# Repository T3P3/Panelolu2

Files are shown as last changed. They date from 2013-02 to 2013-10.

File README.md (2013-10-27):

Panelolu2
=========

An I2C control solution for Sanguinololu, Melzi and more

by tony@think3dprint3d.com

see
http://blog.think3dprint3d.com/2013/02/panelolu2.html
for details

GPL V3

Contents:

- Eagle files for the Panelolu2 circuit board.

- Eagle files for the Sanguinololu and Melzi adapter boards. 

- SCAD files for the case (note still a work in progress)

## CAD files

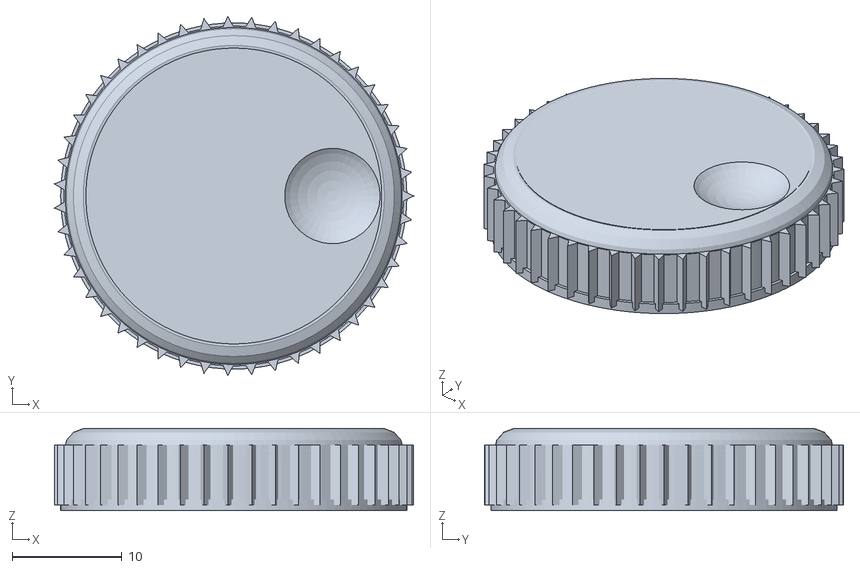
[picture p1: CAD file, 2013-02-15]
Knob_panelolu2.stl
32.8 x 32.8 x 7.50

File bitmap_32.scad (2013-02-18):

/*
Bitmap and 32Bit Font Module based on
Bitmap and 8Bit Font Module
Tony Buser <tbuser@gmail.com>
http://tonybuser.com
http://creativecommons.org/licenses/by/3.0/

Font mapped is Lucida Console fixed width - 32 bit high, 20 bit wide
Bitmap characters are 31 bits high and 8,16,24 or 32 bits wide

tony@think3dprint3d.com
http://blog.think3dprint3d.com/2013/02/bitmap32.html
*/

font_column_bits=31;
//font_row_bits=20; //varies

module bitmap(bitmap, block_size, height, column_bits, row_bits) {
	x_length = block_size * row_bits;
	y_length = block_size * column_bits;
	bitmap_size = row_bits * column_bits;

	function loc_y(loc) = floor(loc / row_bits) * block_size;
	function loc_x(loc) = loc % row_bits * block_size;
	function loc_z(loc) = (bitmap[loc]*height-height)/2;

	translate(v = [-x_length/2+block_size/2,-y_length/2+block_size/2,height/2]) {
		for (loc = [0:bitmap_size - 1]) {
			if (bitmap[loc] != 0) {
				union() {
					translate(v = [loc_x(loc), loc_y(loc), loc_z(loc)]) {
						cube(size = [block_size+0.01, block_size+0.01, height * bitmap[loc]], center = true);
						//echo(str("loc: ",loc," loc_x: ", loc_x(loc) , " loc_y: ",  loc_y(loc)));
					}
				}
			}
		}
	}
}

module 32bit_char(char, block_size, height) {
		if (char == "!") {
	 bitmap([
		0,0,0,0,0,0,0,0,      
		0,0,0,0,0,0,0,0,      
		1,1,1,1,1,0,0,0, 
		1,1,1,1,1,0,0,0, 
		1,1,1,1,1,0,0,0, 
		1,1,1,1,1,0,0,0, 
		1,1,1,1,1,0,0,0, 
		1,1,1,1,1,0,0,0, 
		1,1,1,1,1,0,0,0, 
		1,1,1,1,1,0,0,0, 
		1,1,1,1,1,0,0,0, 
		1,1,1,1,1,0,0,0, 
		1,1,1,1,1,0,0,0, 
		1,1,1,1,1,0,0,0, 
		1,1,1,1,1,0,0,0, 
		1,1,1,1,1,0,0,0, 
		1,1,1,1,1,0,0,0, 
		1,1,1,1,1,0,0,0, 
		1,1,1,1,1,0,0,0, 
		1,1,1,1,1,0,0,0, 
		1,1,1,1,1,0,0,0, 
		0,0,0,0,0,0,0,0,      
		0,0,0,0,0,0,0,0,      
		0,0,0,0,0,0,0,0,      
		1,1,1,1,1,0,0,0, 
		1,1,1,1,1,0,0,0, 
		1,1,1,1,1,0,0,0, 
		0,0,0,0,0,0,0,0,      
		0,0,0,0,0,0,0,0,      
		0,0,0,0,0,0,0,0,      
		0,0,0,0,0,0,0,0      
			], block_size, height, font_column_bits, 8);
	}
		else if (char == "\"") {
		 bitmap([
		1,1,1,1,1,0,1,1,1,1,1,0,0,0,0,0,  
		1,1,1,1,1,0,1,1,1,1,1,0,0,0,0,0,  
		1,1,1,1,1,0,1,1,1,1,1,0,0,0,0,0,  
		1,1,1,1,1,0,1,1,1,1,1,0,0,0,0,0,  
		1,1,1,1,1,0,1,1,1,1,1,0,0,0,0,0,  
		1,1,1,1,1,0,1,1,1,1,1,0,0,0,0,0,  
		1,1,1,1,1,0,1,1,1,1,1,0,0,0,0,0,  
		1,1,1,1,1,0,1,1,1,1,1,0,0,0,0,0,  
		0,0,0,0,0,0,0,0,0,0,0,0,0,0,0,0,            
		0,0,0,0,0,0,0,0,0,0,0,0,0,0,0,0,            
		0,0,0,0,0,0,0,0,0,0,0,0,0,0,0,0,            
		0,0,0,0,0,0,0,0,0,0,0,0,0,0,0,0,            
		0,0,0,0,0,0,0,0,0,0,0,0,0,0,0,0,            
		0,0,0,0,0,0,0,0,0,0,0,0,0,0,0,0,            
		0,0,0,0,0,0,0,0,0,0,0,0,0,0,0,0,            
		0,0,0,0,0,0,0,0,0,0,0,0,0,0,0,0,            
		0,0,0,0,0,0,0,0,0,0,0,0,0,0,0,0,            
		0,0,0,0,0,0,0,0,0,0,0,0,0,0,0,0,            
		0,0,0,0,0,0,0,0,0,0,0,0,0,0,0,0,            
		0,0,0,0,0,0,0,0,0,0,0,0,0,0,0,0,            
		0,0,0,0,0,0,0,0,0,0,0,0,0,0,0,0,            
		0,0,0,0,0,0,0,0,0,0,0,0,0,0,0,0,            
		0,0,0,0,0,0,0,0,0,0,0,0,0,0,0,0,            
		0,0,0,0,0,0,0,0,0,0,0,0,0,0,0,0,            
		0,0,0,0,0,0,0,0,0,0,0,0,0,0,0,0,            
		0,0,0,0,0,0,0,0,0,0,0,0,0,0,0,0,            
		0,0,0,0,0,0,0,0,0,0,0,0,0,0,0,0,            
		0,0,0,0,0,0,0,0,0,0,0,0,0,0,0,0,            
		0,0,0,0,0,0,0,0,0,0,0,0,0,0,0,0,            
		0,0,0,0,0,0,0,0,0,0,0,0,0,0,0,0,            
		0,0,0,0,0,0,0,0,0,0,0,0,0,0,0,0            
			], block_size, height, font_column_bits, 16);
	}
		else if (char == "#") {
		 bitmap([
		0,0,0,0,0,0,0,0,0,0,0,0,0,0,0,0,0,0,0,0,0,0,0,0,                        
		0,0,0,0,0,0,0,0,0,0,0,0,0,0,0,0,0,0,0,0,0,0,0,0,                        
		0,0,0,0,0,0,0,0,0,0,1,1,1,0,0,0,0,1,1,1,0,0,0,0,                  
		0,0,0,0,0,0,0,0,0,1,1,1,1,0,0,0,1,1,1,1,0,0,0,0,                
		0,0,0,0,0,0,0,0,0,1,1,1,0,0,0,0,1,1,1,0,0,0,0,0,                  
		0,0,0,0,0,0,0,0,0,1,1,1,0,0,0,0,1,1,1,0,0,0,0,0,                  
		0,0,0,0,0,0,0,0,0,1,1,1,0,0,0,0,1,1,1,0,0,0,0,0,                  
		0,0,0,0,0,0,0,0,1,1,1,1,0,0,0,1,1,1,1,0,0,0,0,0,                
		0,0,0,0,0,0,0,0,1,1,1,0,0,0,0,1,1,1,0,0,0,0,0,0,                  
		0,0,0,0,0,0,0,0,1,1,1,0,0,0,0,1,1,1,0,0,0,0,0,0,                  
		0,0,1,1,1,1,1,1,1,1,1,1,1,1,1,1,1,1,1,1,1,1,1,0,   
		0,0,1,1,1,1,1,1,1,1,1,1,1,1,1,1,1,1,1,1,1,1,1,0,   
		0,0,0,0,0,0,0,1,1,1,0,0,0,0,1,1,1,0,0,0,0,0,0,0,                  
		0,0,0,0,0,0,0,1,1,1,0,0,0,0,1,1,1,0,0,0,0,0,0,0,                  
		0,0,0,0,0,0,1,1,1,1,0,0,0,1,1,1,1,0,0,0,0,0,0,0,                
		0,0,0,0,0,0,1,1,1,0,0,0,0,1,1,1,0,0,0,0,0,0,0,0,                  
		0,0,0,0,0,0,1,1,1,0,0,0,0,1,1,1,0,0,0,0,0,0,0,0,                  
		1,1,1,1,1,1,1,1,1,1,1,1,1,1,1,1,1,1,1,1,1,0,0,0,   
		1,1,1,1,1,1,1,1,1,1,1,1,1,1,1,1,1,1,1,1,1,0,0,0,   
		0,0,0,0,0,1,1,1,0,0,0,0,1,1,1,0,0,0,0,0,0,0,0,0,                  
		0,0,0,0,0,1,1,1,0,0,0,0,1,1,1,0,0,0,0,0,0,0,0,0,                  
		0,0,0,0,1,1,1,1,0,0,0,1,1,1,1,0,0,0,0,0,0,0,0,0,                
		0,0,0,0,1,1,1,0,0,0,0,1,1,1,0,0,0,0,0,0,0,0,0,0,                  
		0,0,0,0,1,1,1,0,0,0,0,1,1,1,0,0,0,0,0,0,0,0,0,0,                  
		0,0,0,0,1,1,1,0,0,0,0,1,1,1,0,0,0,0,0,0,0,0,0,0,                  
		0,0,0,1,1,1,1,0,0,0,1,1,1,1,0,0,0,0,0,0,0,0,0,0,                
		0,0,0,1,1,1,0,0,0,0,1,1,1,0,0,0,0,0,0,0,0,0,0,0,                  
		0,0,0,0,0,0,0,0,0,0,0,0,0,0,0,0,0,0,0,0,0,0,0,0,                        
		0,0,0,0,0,0,0,0,0,0,0,0,0,0,0,0,0,0,0,0,0,0,0,0,                        
		0,0,0,0,0,0,0,0,0,0,0,0,0,0,0,0,0,0,0,0,0,0,0,0,                        
		0,0,0,0,0,0,0,0,0,0,0,0,0,0,0,0,0,0,0,0,0,0,0,0                        
			], block_size, height, font_column_bits, 24);
	}
		else if (char == "$") {
		 bitmap([
		0,0,0,0,0,0,0,1,1,1,0,0,0,0,0,0,             
		0,0,0,0,0,0,0,1,1,1,0,0,0,0,0,0,             
		0,0,0,0,0,1,1,1,1,1,1,1,1,0,0,0,        
		0,0,0,1,1,1,1,1,1,1,1,1,1,1,1,0,    
		0,0,1,1,1,1,1,1,1,1,0,1,1,1,1,0,    
		0,0,1,1,1,1,0,1,1,1,0,0,0,1,1,0,       
		0,1,1,1,1,0,0,1,1,1,0,0,0,0,0,0,         
		0,1,1,1,1,0,0,1,1,1,0,0,0,0,0,0,         
		0,1,1,1,1,0,0,1,1,1,0,0,0,0,0,0,         
		0,1,1,1,1,0,0,1,1,1,0,0,0,0,0,0,         
		0,1,1,1,1,1,0,1,1,1,0,0,0,0,0,0,        
		0,0,1,1,1,1,1,1,1,1,0,0,0,0,0,0,        
		0,0,0,1,1,1,1,1,1,1,0,0,0,0,0,0,         
		0,0,0,0,1,1,1,1,1,1,0,0,0,0,0,0,          
		0,0,0,0,0,1,1,1,1,1,1,1,0,0,0,0,         
		0,0,0,0,0,0,0,1,1,1,1,1,1,0,0,0,          
		0,0,0,0,0,0,0,1,1,1,1,1,1,1,0,0,         
		0,0,0,0,0,0,0,1,1,1,1,1,1,1,1,0,        
		0,0,0,0,0,0,0,1,1,1,0,1,1,1,1,0,         
		0,0,0,0,0,0,0,1,1,1,0,1,1,1,1,0,         
		0,0,0,0,0,0,0,1,1,1,0,1,1,1,1,0,         
		0,0,0,0,0,0,0,1,1,1,0,1,1,1,1,0,         
		0,0,0,0,0,0,0,1,1,1,1,1,1,1,1,0,        
		1,1,1,0,0,0,0,1,1,1,1,1,1,1,0,0,      
		1,1,1,1,1,1,1,1,1,1,1,1,1,1,0,0,  
		1,1,1,1,1,1,1,1,1,1,1,1,1,0,0,0,   
		0,0,1,1,1,1,1,1,1,1,1,0,0,0,0,0,       
		0,0,0,0,0,0,0,1,1,1,0,0,0,0,0,0,             
		0,0,0,0,0,0,0,1,1,1,0,0,0,0,0,0,             
		0,0,0,0,0,0,0,0,0,0,0,0,0,0,0,0,                
		0,0,0,0,0,0,0,0,0,0,0,0,0,0,0,0                
			], block_size, height, font_column_bits, 16);
	}
		else if (char == "%") {
		 bitmap([
		0,0,0,0,0,0,0,0,0,0,0,0,0,0,0,0,0,0,0,0,0,0,0,0,                         
		0,0,0,0,0,0,0,0,0,0,0,0,0,0,0,0,0,0,0,0,1,1,1,0,                      
		0,0,0,1,1,1,1,1,1,0,0,0,0,0,0,0,0,0,0,1,1,1,1,0,               
		0,0,1,1,1,1,1,1,1,1,0,0,0,0,0,0,0,0,1,1,1,1,0,0,             
		0,1,1,1,1,0,0,1,1,1,1,0,0,0,0,0,0,0,1,1,1,0,0,0,              
		1,1,1,1,1,0,0,1,1,1,1,1,0,0,0,0,0,1,1,1,0,0,0,0,            
		1,1,1,1,0,0,0,0,1,1,1,1,0,0,0,0,1,1,1,1,0,0,0,0,             
		1,1,1,1,0,0,0,0,1,1,1,1,0,0,0,1,1,1,1,0,0,0,0,0,             
		1,1,1,1,0,0,0,0,1,1,1,1,0,0,0,1,1,1,0,0,0,0,0,0,              
		1,1,1,1,0,0,0,0,1,1,1,1,0,0,1,1,1,1,0,0,0,0,0,0,             
		1,1,1,1,0,0,0,0,1,1,1,1,0,1,1,1,1,0,0,0,0,0,0,0,             
		1,1,1,1,1,0,0,1,1,1,1,1,1,1,1,1,0,0,0,0,0,0,0,0,           
		0,1,1,1,1,0,0,1,1,1,1,0,1,1,1,0,0,0,0,0,0,0,0,0,              
		0,0,1,1,1,1,1,1,1,1,0,1,1,1,1,0,0,0,0,0,0,0,0,0,             
		0,0,0,1,1,1,1,1,1,0,1,1,1,1,0,1,1,1,1,1,1,0,0,0,         
		0,0,0,0,0,0,0,0,0,1,1,1,1,0,1,1,1,1,1,1,1,1,0,0,             
		0,0,0,0,0,0,0,0,0,1,1,1,0,1,1,1,1,0,0,1,1,1,1,0,              
		0,0,0,0,0,0,0,0,1,1,1,1,1,1,1,1,1,0,0,1,1,1,1,1,           
		0,0,0,0,0,0,0,1,1,1,1,0,1,1,1,1,0,0,0,0,1,1,1,1,             
		0,0,0,0,0,0,1,1,1,1,0,0,1,1,1,1,0,0,0,0,1,1,1,1,             
		0,0,0,0,0,0,1,1,1,0,0,0,1,1,1,1,0,0,0,0,1,1,1,1,              
		0,0,0,0,0,1,1,1,1,0,0,0,1,1,1,1,0,0,0,0,1,1,1,1,             
		0,0,0,0,1,1,1,1,0,0,0,0,1,1,1,1,0,0,0,0,1,1,1,1,             
		0,0,0,0,1,1,1,0,0,0,0,0,1,1,1,1,1,0,0,1,1,1,1,1,            
		0,0,0,1,1,1,0,0,0,0,0,0,0,1,1,1,1,0,0,1,1,1,1,0,              
		0,0,1,1,1,1,0,0,0,0,0,0,0,0,1,1,1,1,1,1,1,1,0,0,             
		0,1,1,1,1,0,0,0,0,0,0,0,0,0,0,1,1,1,1,1,1,0,0,0,               
		0,1,1,1,0,0,0,0,0,0,0,0,0,0,0,0,0,0,0,0,0,0,0,0,
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

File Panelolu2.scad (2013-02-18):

// Panelolu2 housing v0.1
//
// based on the Panelolu housing:
// thingiverse:http://www.thingiverse.com/thing:25617
//
// For more information:
// http://blog.think3dprint3d.com/2013/02/panelolu2.html
//
// by Tony Lock
// GNU GPL v3
// Feb 2013

/*
@todo:
- Integrate the knob code
- colour the assembly + provide exploded view
*/

//tony Busers bitmap letters, changed to (almost) 32 bit
include <bitmap_32.scad>;

///////////////////////////////////////////////////////////
//front, back or legs
///////////////////////////////////////////////////////////
side=-1; //1 = front, -1 = back  2= legs  0=assembly model
///////////////////////////////////////////////////////////

// Bed cube for layout
//translate([0,0,-0.5])
//cube([195,195,1], center=true);

////////////////////////////////////////////////////////////////////
//originally from Prusa configuration.scad
//https://github.com/prusajr/PrusaMendel
////////////////////////////////////////////////////////////////////
m3_diameter = 3.6;
m3_nut_diameter = 5.3;
m3_nut_diameter_bigger=((m3_nut_diameter / 2) / cos (180 / 6))*2;
////////////////////////////////////////////////////////////////////
clearance=1.2;
wall_width=1.6; //minimum wall width //should be a multiple of your extruded dia
layer_height=0.2;
//LCD screen
lcd_scrn_w=98+clearance;
lcd_scrn_h=39.8+clearance;
lcd_scrn_z=9.4;

lcd_board_w=98.5 + clearance;
lcd_board_h=60.5 + clearance/2;
lcd_board_z=1.6; //does not include metal tabs on base

lcd_hole_d=3.4;
lcd_hole_offset=(lcd_hole_d/2)+1;

//board edge to center of first connector hole
lcd_connect_x=9.8;  
lcd_connect_y=2.6;

//Panelolu2 circuit board

p2_w=lcd_board_w;
p2_h=25 + clearance/2;
p2_z=4; //excluding LEDs, click Encoder, reset switch and headers
p2_mounting_hole_dia=2.5;
p2_mounting_hole1_x=10;
p2_mounting_hole2_x=66;
p2_mounting_hole_y=2;

//rotary encoder
click_encoder_w=13.2;
click_encoder_h=12.6;
click_encoder_z=6;
click_encoder_shaft_dia=6.9+clearance;
click_encoder_shaft_h=14.2;
click_encoder_knob_dia=28.6;
click_encoder_knob_t=8;
click_encoder_offset_x=61.8;
click_encoder_offset_y=11;

//buzzer
bz_dia=12;
bz_offset_x=13.7;
bz_offset_y=10.6;

//LEDs
led_dia=5; //3 on production boards
led_z=12.5;
led_offset_y=3.5;
led1_offset_x=20.6;
led2_offset_x=33.5;
led3_offset_x=46.4;

//reset switch
reset_z=17.1;
reset_dia=4+clearance; //at point switch goes through case
reset_offset_x=24.9;
reset_offset_y=11.1;

//contrast and brightness holes
cb_dia=4;
con_x=66.7;
con_y=17.4;
bri_x=56.6;
bri_y=17.4;
//headers
//lcd connection header
lcd_h_w=(16*2.54)+2.54;
lcd_h_h=2.54;
lcd_h_z=3; //2.5 on production model, this is the gap between the circuit board caused by the plastic spaces on 2.54mm headers
lcd_h_offset_x=lcd_connect_x;  //unlike other measurements this is to first hole not center of object
lcd_h_offset_y=lcd_connect_y;

//IDC header, use the clearance required for the plug
idc_h_w=8;
idc_h_h=22;
idc_h_z=18.3; //not all will be within case
idc_offset_x=1.5; //to edge not to center
idc_offset_y=1;  

//SD card slot
SD_slot_h=15;
SD_slot_z=4;
SD_slot_offset_y=6;

//case closing lugs
lug_dia = lcd_hole_d+lcd_hole_offset+wall_width*1.8;

//letters variables
char_block_size = 0.3; //20 blocks wide by 32 high
char_height = 3.5;

//for legs
LCD_incline_angle=45;

//////////////////////////////////////////////////////////////////////////////////////////
// front
if (side==1)
{
	panelolu2_front();
}

// back
else if(side==-1)
{
	panelolu2_back();
}
//legs
else if(side==2)
{
	//rotate([-90-LCD_incline_angle,0,0])
	//leg_back(angle= LCD_incline_angle,standoff_height=9);
	front_standoff(standoff_height=9);
}
//assembly
else
{
  //whatever we want to test
  panelolu2_back();
  translate([0,0,(p2_z+lcd_h_z+wall_width+1.6)+(led_z-lcd_h_z-lcd_board_z)])
	rotate([0,180,0])
		panelolu2_front();
  translate([0,(p2_h-2*lcd_connect_y)/2,wall_width])
	#internal_assembly();
  //alignment still to be done
  /*
    translate([0,(lcd_board_h)/2,-(p2_z+lcd_h_z+wall_width+1.6)-(led_z-lcd_h_z-lcd_board_z)])
	rotate([LCD_incline_angle-90,0,180])
		leg_back(angle=LCD_incline_angle,standoff_height=9);
	*/
}
//////////////////////////////////////////////////////////////////////////////////////////

module panelolu2_front() {
	front_t=led_z-lcd_h_z-lcd_board_z; //the top of the front is flush with the top of the LEDs
	tabs_z=front_t-layer_height*2; //the LCD circuit board support tabs 
	difference() {
		union() {
			difference() {
				union(){
					//LCD board +P2 circuit board area 
					translate([0, 0, 0])
						roundedRect([lcd_board_w+wall_width,lcd_board_h+p2_h+wall_width-(2*lcd_connect_y),front_t], wall_width+1);
					//mounting lugs
					for(i=[1,-1]) {
					translate([i*((lcd_board_w-lug_dia-0.7)/2+wall_width),lcd_connect_y-(lcd_board_h+p2_h)/2-2*lug_dia/3,front_t/2])
						cylinder(r=(lug_dia+1.4)/2,h=front_t,$fn=12,center=true);
					translate([i*((lcd_board_w-lug_dia-0.7)/2+wall_width),lcd_connect_y-(lcd_board_h+p2_h)/2-lug_dia/6,front_t/2])
						cube([lug_dia+1.4,lug_dia, front_t], center=true);
					}
				}
				//lcd and Panelolu2 board cutouts
				translate([0,0,front_t/2+wall_width])
					cube([lcd_board_w,lcd_board_h+p2_h-2*lcd_connect_y, front_t], center=true);

				//Screen cutout
				translate([0,(p2_h-2*lcd_connect_y)/2,-wall_width]) 
					cube([lcd_scrn_w,lcd_scrn_h,lcd_scrn_z], center=true);
			}
			//LCD supports
			lcd_screw_support(tabs_z,18);		
		}

		//cut outs Encoder, reset, LED holes and buzzer //mirrored on X as top is inverter for mounting
		mirror([1,0,0]) {
			translate([click_encoder_offset_x-(lcd_board_w)/2,click_encoder_offset_y-(lcd_board_h+p2_h-lcd_connect_y*2)/2,-wall_width/2])
				cylinder(r=click_encoder_shaft_dia/2,h=wall_width*2,$fn=12);
			translate([reset_offset_x-(lcd_board_w)/2,reset_offset_y-(lcd_board_h+p2_h-lcd_connect_y*2)/2,-wall_width/2])
				cylinder(r=reset_dia/2,h=wall_width*2,$fn=12);
			translate([led1_offset_x-(lcd_board_w)/2,led_offset_y-(lcd_board_h+p2_h-lcd_connect_y*2)/2,-wall_width/2])
				cylinder(r=led_dia/2,h=wall_width*2,$fn=12);
			translate([led2_offset_x-(lcd_board_w)/2,led_offset_y-(lcd_board_h+p2_h-lcd_connect_y*2)/2,-wall_width/2])
				cylinder(r=led_dia/2,h=wall_width*2,$fn=12);
			translate([led3_offset_x-(lcd_board_w)/2,led_offset_y-(lcd_board_h+p2_h-lcd_connect_y*2)/2,-wall_width/2])
				cylinder(r=led_dia/2,h=wall_width*2,$fn=12);
			translate([bz_offset_x-(lcd_board_w)/2,bz_offset_y-(lcd_board_h+p2_h-lcd_connect_y*2)/2+3,-wall_width/2])
				buzzer_grid();
			//labels
			translate([reset_offset_x-(lcd_board_w)/2+1.5,reset_offset_y-(lcd_board_h+p2_h-lcd_connect_y*2)/2+7,-char_height+wall_width-layer_height*2])
				rotate([0,0,270])
						32bit_str("R", 1, char_block_size, char_height);
			translate([led1_offset_x-(lcd_board_w)/2-6,led_offset_y-(lcd_board_h+p2_h-lcd_connect_y*2)/2,-char_height+wall_width-layer_height*2])
				rotate([0,0,270])
						32bit_str("H", 1, char_block_size, char_height);
			translate([led2_offset_x-(lcd_board_w)/2-6,led_offset_y-(lcd_board_h+p2_h-lcd_connect_y*2)/2,-char_height+wall_width-layer_height*2])
				rotate([0,0,270])
						32bit_str("E", 1, char_block_size, char_height);
			translate([led3_offset_x-(lcd_board_w)/2-6,led_offset_y-(lcd_board_h+p2_h-lcd_connect_y*2)/2,-char_height+wall_width-layer_height*2])
				rotate([0,0,270])
						32bit_str("F", 1, char_block_size, char_height);
			}
			
		//mounting screw holes
		translate([0,-lug_dia/2,19])
			rotate([0,180,0])
				lcd_screw_holes(nut_trap=false,fn=8, dia=lcd_hole_d+0.2,extension_hole=true);
	}

}

module panelolu2_back() {
	back_t=p2_z+lcd_h_z+wall_width+1.6; //1.6 is the thickness of the LCD pcb excluding all the stuff at the back
	tabs_z=back_t-1.6-layer_height*2; //the LCD circuit board support tabs 
	difference() {
		union() {
			difference() {
				union(){
					//LCD board +P2 circuit board area 
					translate([0, 0, 0])
						roundedRect([lcd_board_w+wall_width,lcd_board_h+p2_h+wall_width-(2*lcd_connect_y),back_t], wall_width+1);
					//mounting lugs
					for(i=[1,-1]) {
					translate([i*((lcd_board_w-lug_dia-0.7)/2+wall_width),lcd_connect_y-(lcd_board_h+p2_h)/2-2*lug_dia/3,back_t/2])
						cylinder(r=(lug_dia+1.4)/2,h=back_t,$fn=12,center=true);
					translate([i*((lcd_board_w-lug_dia-0.7)/2+wall_width),lcd_connect_y-(lcd_board_h+p2_h)/2-lug_dia/6,back_t/2])
						cube([lug_dia+1.4,lug_dia, back_t], center=true);
					}
				}
				//lcd and Panelolu2 board cutouts
				translate([0,0,back_t/2+wall_width])
					cube([lcd_board_w,lcd_board_h+p2_h-2*lcd_connect_y, back_t], center=true);
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

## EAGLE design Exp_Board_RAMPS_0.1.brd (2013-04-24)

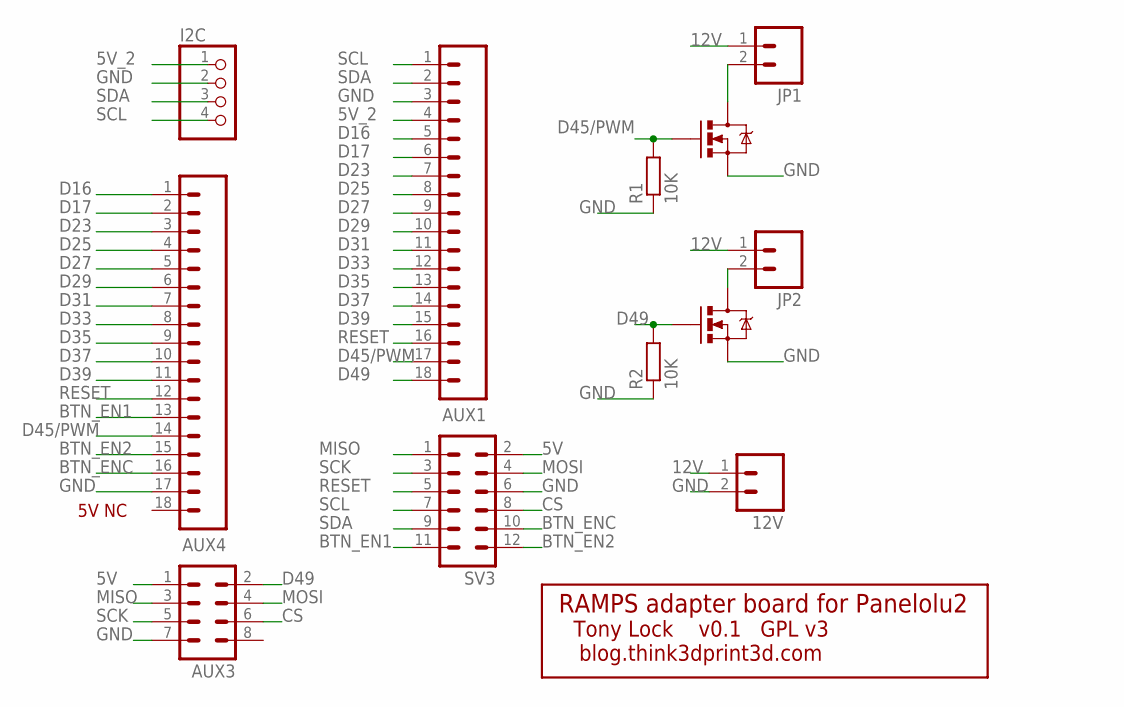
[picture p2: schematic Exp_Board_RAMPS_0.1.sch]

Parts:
12V: M02PTH; 1X02
AUX1, AUX4: SPARKFUN_M18_; SPARKFUN_1X18
AUX3: MA04-2
I2C: REPRAPJR_PINHD-1X4; REPRAPJR_1X04
JP1, JP2: M02PTH; 1X02
Q1: Transistor1; TO220V
Q2: Transistor2; TO220V
R1, R2: 10K; 0204/7
SV3: MA06-2_BACK

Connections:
5V: AUX3.1, SV3.2
5V_2: AUX1.4, I2C.1
12V: 12V.1, JP1.1, JP2.1
BTN_EN1: AUX4.13, SV3.11
BTN_EN2: AUX4.15, SV3.12
BTN_ENC: AUX4.16, SV3.10
CS: AUX3.6, SV3.8
D16: AUX1.5, AUX4.1
D17: AUX1.6, AUX4.2
D23: AUX1.7, AUX4.3
D25: AUX1.8, AUX4.4
D27: AUX1.9, AUX4.5
D29: AUX1.10, AUX4.6
D31: AUX1.11, AUX4.7
D33: AUX1.12, AUX4.8
D35: AUX1.13, AUX4.9
D37: AUX1.14, AUX4.10
D39: AUX1.15, AUX4.11
D45/PWM: AUX1.17, AUX4.14, Q1.1 (G), R1.2
D49: AUX1.18, AUX3.2, Q2.1 (G), R2.2
GND: 12V.2, AUX1.3, AUX3.7, AUX4.17, I2C.2, Q1.3 (S), Q2.3 (S), R1.1, R2.1, SV3.6
MISO: AUX3.3, SV3.1
MOSI: AUX3.4, SV3.4
unnamed: JP1.2, Q1.2 (D)
unnamed: JP2.2, Q2.2 (D)
RESET: AUX1.16, AUX4.12, SV3.5
SCK: AUX3.5, SV3.3
SCL: AUX1.1, I2C.4, SV3.7
SDA: AUX1.2, I2C.3, SV3.9

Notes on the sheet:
RAMPS adapter board for Panelolu2
Tony Lock v0.1 GPL v3
blog.think3dprint3d.com
5V NC

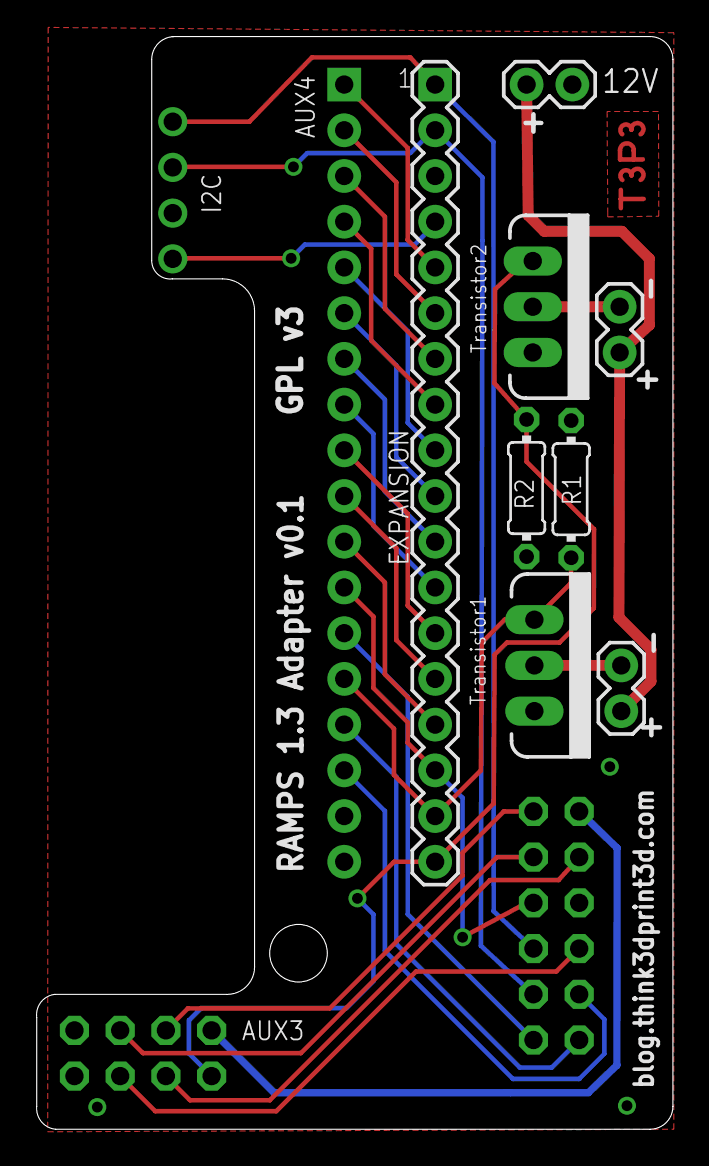
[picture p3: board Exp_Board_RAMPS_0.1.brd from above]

Board: 2 copper layers, 35.4 x 60.7 mm, 12 parts (0 on the bottom side), 29 nets.

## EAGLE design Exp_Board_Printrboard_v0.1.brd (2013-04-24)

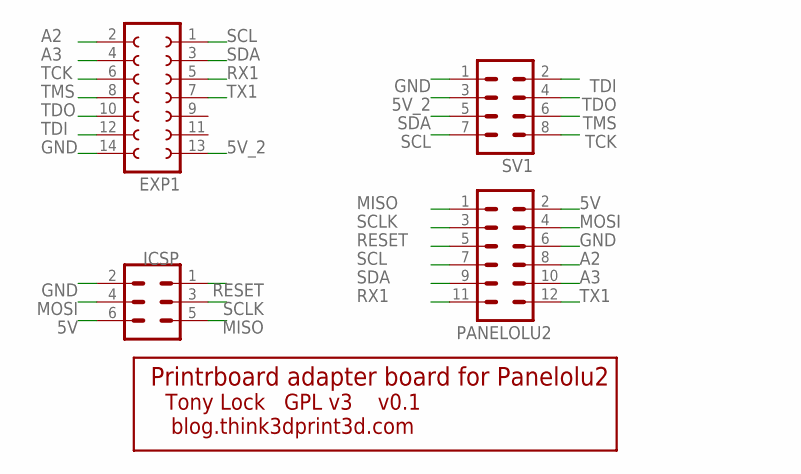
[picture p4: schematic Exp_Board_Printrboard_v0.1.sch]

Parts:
EXP1: FE07-2
ICSP: MA03-2
PANELOLU2: MA06-2_BACK
SV1: MA04-2

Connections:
5V: ICSP.6, PANELOLU2.2
5V_2: EXP1.13, SV1.3
A2: EXP1.2, PANELOLU2.8
A3: EXP1.4, PANELOLU2.10
GND: EXP1.14, ICSP.2, PANELOLU2.6, SV1.1
MISO: ICSP.5, PANELOLU2.1
MOSI: ICSP.4, PANELOLU2.4
RESET: ICSP.1, PANELOLU2.5
RX1: EXP1.5, PANELOLU2.11
SCL: EXP1.1, PANELOLU2.7, SV1.7
SCLK: ICSP.3, PANELOLU2.3
SDA: EXP1.3, PANELOLU2.9, SV1.5
TCK: EXP1.6, SV1.8
TDI: EXP1.12, SV1.2
TDO: EXP1.10, SV1.4
TMS: EXP1.8, SV1.6
TX1: EXP1.7, PANELOLU2.12

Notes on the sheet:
Printrboard adapter board for Panelolu2
Tony Lock GPL v3 v0.1
blog.think3dprint3d.com

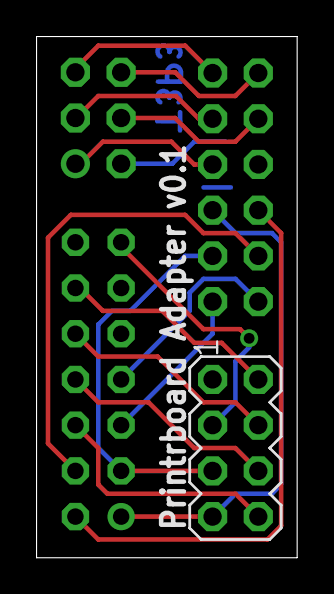
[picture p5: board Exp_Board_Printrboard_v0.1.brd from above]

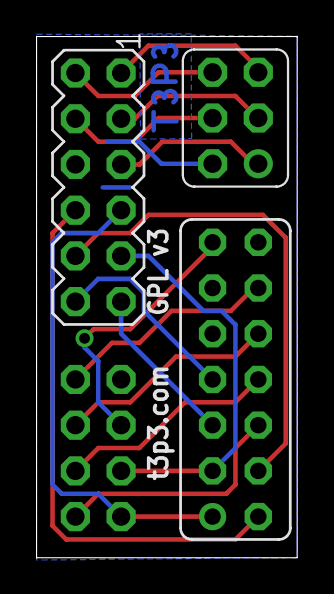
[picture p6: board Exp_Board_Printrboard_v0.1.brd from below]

Board: 2 copper layers, 14.5 x 29.0 mm, 4 parts (2 on the bottom side), 17 nets.

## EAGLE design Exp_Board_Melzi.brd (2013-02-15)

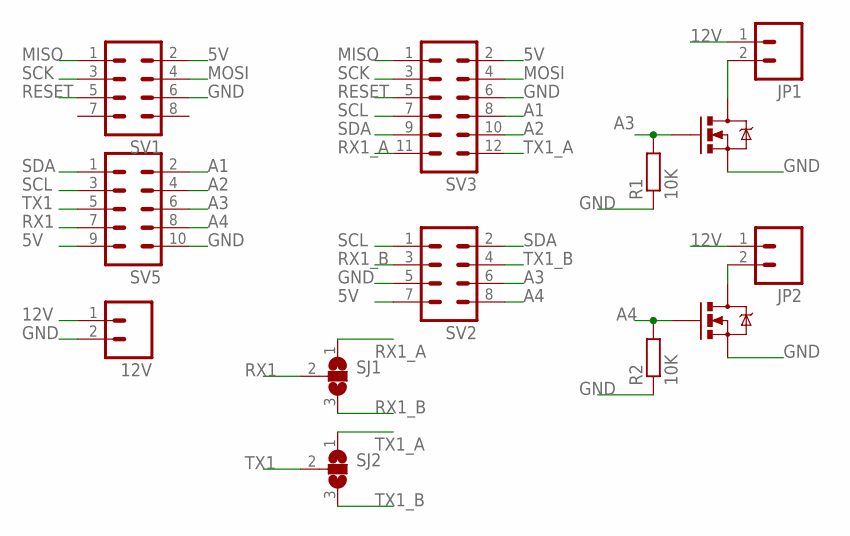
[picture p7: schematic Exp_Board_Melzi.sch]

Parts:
12V: M02PTH; 1X02
JP1, JP2: M02PTH; 1X02
Q1: Transistor1; TO220V
Q2: Transistor2; TO220V
R1, R2: 10K; 0204/7
SJ1, SJ2: SJ2W; SJ_2
SV1, SV2: MA04-2
SV3: MA06-2
SV5: MA05-2

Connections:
5V: SV1.2, SV2.7, SV3.2, SV5.9
12V: JP1.1, JP2.1
A1: SV3.8, SV5.2
A2: SV3.10, SV5.4
A3: Q1.1 (G), R1.2, SV2.6, SV5.6
A4: Q2.1 (G), R2.2, SV2.8, SV5.8
GND: Q1.3 (S), Q2.3 (S), R1.1, R2.1, SV1.6, SV2.5, SV3.6, SV5.10
MISO: SV1.1, SV3.1
MOSI: SV1.4, SV3.4
unnamed: JP1.2, Q1.2 (D)
unnamed: JP2.2, Q2.2 (D)
RESET: SV1.5, SV3.5
RX1: SJ1.2, SV5.7
RX1_A: SJ1.1, SV3.11
RX1_B: SJ1.3, SV2.3
SCK: SV1.3, SV3.3
SCL: SV2.1, SV3.7, SV5.3
SDA: SV2.2, SV3.9, SV5.1
TX1: SJ2.2, SV5.5
TX1_A: SJ2.1, SV3.12
TX1_B: SJ2.3, SV2.4

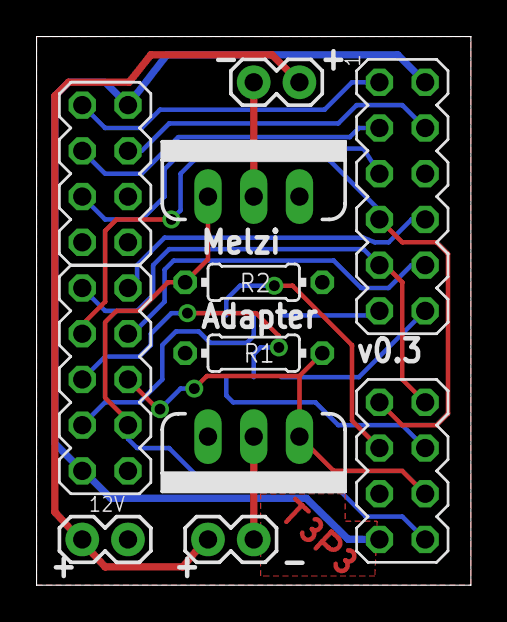
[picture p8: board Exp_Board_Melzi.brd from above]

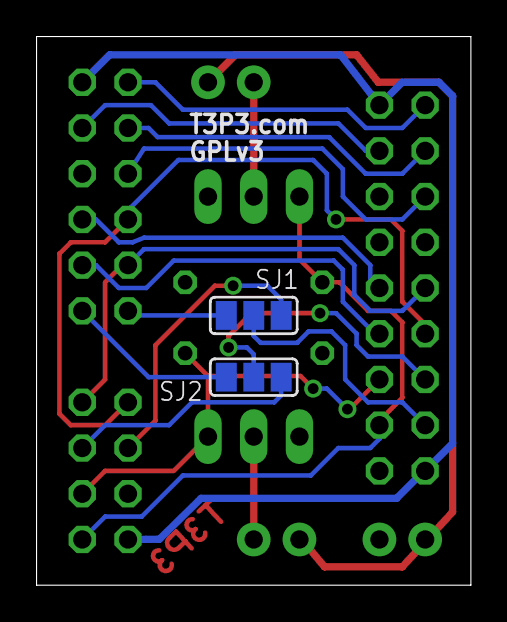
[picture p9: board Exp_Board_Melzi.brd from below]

Board: 2 copper layers, 24.1 x 30.5 mm, 13 parts (2 on the bottom side), 21 nets.

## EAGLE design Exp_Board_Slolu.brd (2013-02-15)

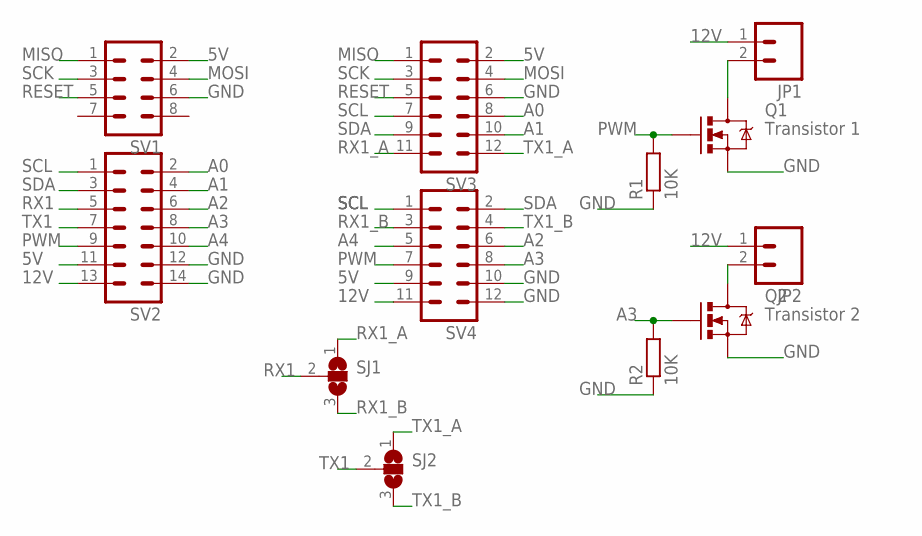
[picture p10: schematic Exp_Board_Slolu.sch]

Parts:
JP1, JP2: M02PTH; 1X02
Q1: Transistor 1; TO220V
Q2: Transistor 2; TO220V
R1, R2: 10K; 0204/7
SJ1, SJ2: SJ2W; SJ_2
SV1: MA04-2
SV2: MA07-2
SV3, SV4: MA06-2

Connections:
5V: SV1.2, SV2.11, SV3.2, SV4.9
12V: JP1.1, JP2.1, SV2.13, SV4.11
A0: SV2.2, SV3.8
A1: SV2.4, SV3.10
A2: SV2.6, SV4.6
A3: Q2.1 (G), R2.2, SV2.8, SV4.8
A4: SV2.10, SV4.5
GND: Q1.3 (S), Q2.3 (S), R1.1, R2.1, SV1.6, SV2.12, SV2.14, SV3.6, SV4.10, SV4.12
MISO: SV1.1, SV3.1
MOSI: SV1.4, SV3.4
unnamed: JP1.2, Q1.2 (D)
unnamed: JP2.2, Q2.2 (D)
PWM: Q1.1 (G), R1.2, SV2.9, SV4.7
RESET: SV1.5, SV3.5
RX1: SJ1.2, SV2.5
RX1_A: SJ1.1, SV3.11
RX1_B: SJ1.3, SV4.3
SCK: SV1.3, SV3.3
SCL: SV2.1, SV3.7, SV4.1
SDA: SV2.3, SV3.9, SV4.2
TX1: SJ2.2, SV2.7
TX1_A: SJ2.1, SV3.12
TX1_B: SJ2.3, SV4.4

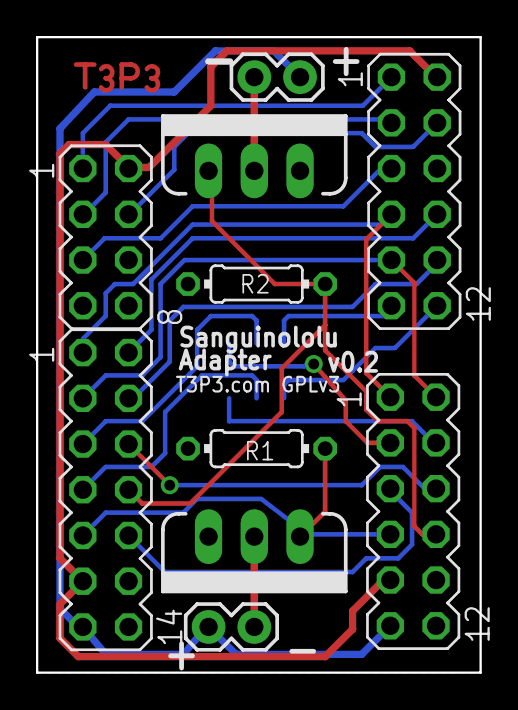
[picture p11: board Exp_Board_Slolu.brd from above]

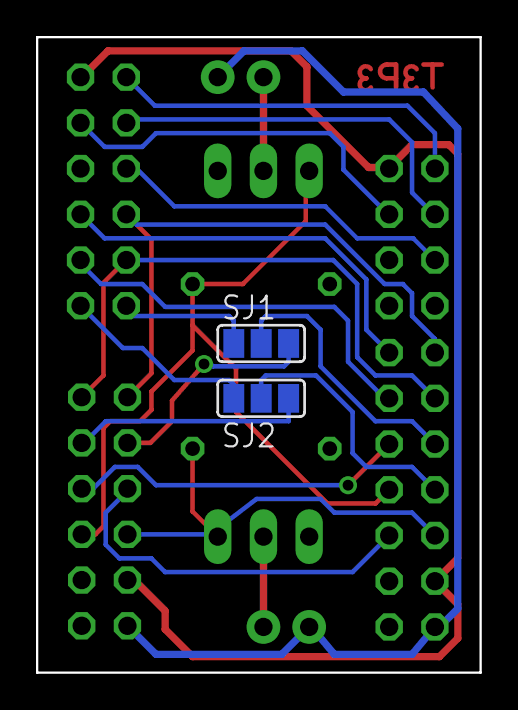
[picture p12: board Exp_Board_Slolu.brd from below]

Board: 2 copper layers, 24.6 x 35.3 mm, 12 parts (2 on the bottom side), 23 nets.

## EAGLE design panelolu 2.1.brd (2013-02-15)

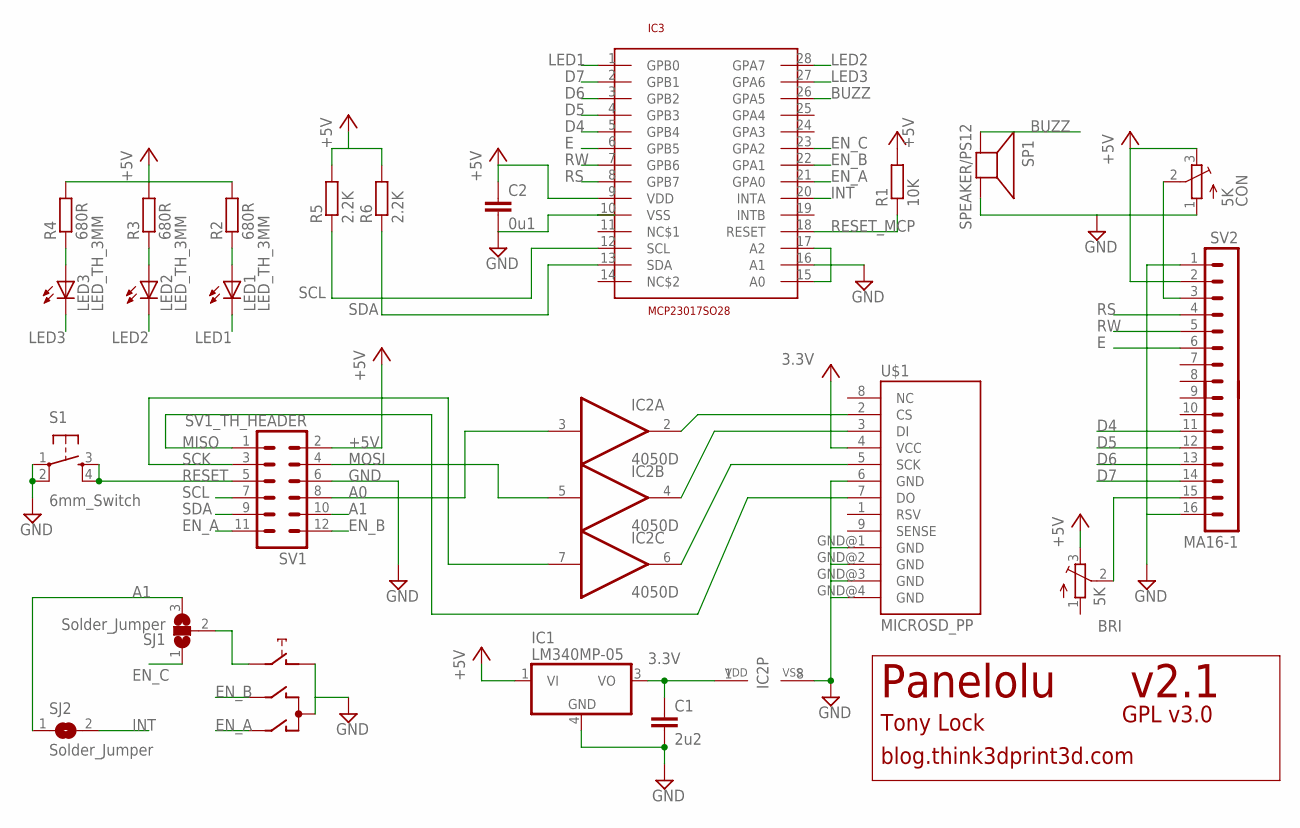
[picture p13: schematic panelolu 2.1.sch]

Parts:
BRI: 5K; TC33X
C1: 2u2; C1206K
C2: 0u1; C0805K
CON: 5K; TC33X
IC1: LM340MP-05; SOT223
IC2: 4050D; SO16
IC3: MCP23017SO28; SO28W
LED1, LED2, LED3: LED_TH_3MM; LED3MM
R1: 10K; M0805
R2, R3, R4: 680R; M0805
R5, R6: 2.2K; M0805
S1: 6mm_Switch; TACTILE-PTH
SJ1: Solder_Jumper; SJ_2
SJ2: Solder_Jumper; SJ
SP1: SPEAKER/PS12; PS12
SV1: SV1_TH_HEADER; MA06-2
SV2: MA16-1
SW1: EC12E_SW; ALPS_EC12E_SW
U$1: MICROSD_PP

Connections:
3.3V: C1.1, IC1.3 (VO), IC2.1 (VDD), U$1.4 (VCC)
+5V: BRI.3 (E), C2.1, CON.3 (E), IC1.1 (VI), IC3.9 (VDD), R1.2, R2.2, R3.2, R4.2, R5.2, R6.2, SV1.2, SV2.2
A0: IC2.3 (I), SV1.8
A1: SJ1.3, SJ2.1, SV1.10
BUZZ: IC3.26 (GPA5), SP1.P$1 (+)
CS3.3: IC2.2 (O), U$1.2 (CS)
D4: IC3.5 (GPB4), SV2.11
D5: IC3.4 (GPB3), SV2.12
D6: IC3.3 (GPB2), SV2.13
D7: IC3.2 (GPB1), SV2.14
DI3.3: IC2.4 (O), U$1.3 (DI)
E: IC3.6 (GPB5), SV2.6
EN_A: IC3.21 (GPA0), SV1.11, SW1.A
EN_B: IC3.22 (GPA1), SV1.12, SW1.B
EN_C: IC3.23 (GPA2), SJ1.1
GND: C1.2, C2.2, CON.1 (A), IC1.4 (GND), IC2.8 (VSS), IC3.10 (VSS), IC3.15 (A0), IC3.16 (A1), IC3.17 (A2), S1.1, S1.2, SP1.P$2 (-), SV1.6, SV2.1, SV2.16, SW1.C, SW1.D (1), U$1.6 (GND), U$1.GND@1 (GND), U$1.GND@2 (GND), U$1.GND@3 (GND), U$1.GND@4 (GND)
INT: IC3.20 (INTA), SJ2.2
LED1: IC3.1 (GPB0), LED1.K (C)
LED2: IC3.28 (GPA7), LED2.K (C)
LED3: IC3.27 (GPA6), LED3.K (C)
MISO: SV1.1, U$1.7 (DO)
MOSI: IC2.5 (I), SV1.4
unnamed: BRI.2 (S), SV2.15
unnamed: CON.2 (S), SV2.3
unnamed: LED1.A, R2.1
unnamed: LED2.A, R3.1
unnamed: LED3.A, R4.1
unnamed: SJ1.2, SW1.E (2)
RESET: S1.3, S1.4, SV1.5
RESET_MCP: IC3.18 (RESET), R1.1
RS: IC3.8 (GPB7), SV2.4
RW: IC3.7 (GPB6), SV2.5
SCK: IC2.7 (I), SV1.3
SCK3.3: IC2.6 (O), U$1.5 (SCK)
SCL: IC3.12 (SCL), R5.1, SV1.7
SDA: IC3.13 (SDA), R6.1, SV1.9

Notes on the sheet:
v2.1
blog.think3dprint3d.com
Tony Lock
GPL v3.0
Panelolu



Board: 2 copper layers, 98.0 x 25.0 mm, 24 parts (16 on the bottom side), 36 nets.

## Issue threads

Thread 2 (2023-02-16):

Encoder signal and sd detect pin

selahattinerdal, 2023-02-16:
Hello, does Marlin 2 support routing the encoder signals over I2C and how can i add sd detect pin to mcp23017. Thanks.

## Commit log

2013-02-15 initial upload of files
    [Exp_Board_Melzi.brd, Exp_Board_Melzi.sch, Exp_Board_Slolu.brd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]
2013-02-15 Added correct link to blog post
    [Panelolu2.scad]
2013-02-18 added bitmap_32.scad and made minor changes to contrast and brightness holes
    [Panelolu2.scad, bitmap_32.scad]
2013-04-09 Slight amendment of schematic
    [Exp_Board_Melzi.sch]
2013-04-24 Added RAMPS1.3 and Printrboard adapter CAD files
    [Exp_Board_Printrboard_v0.1.brd, Exp_Board_Printrboard_v0.1.sch, Exp_Board_RAMPS_0.1.brd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]

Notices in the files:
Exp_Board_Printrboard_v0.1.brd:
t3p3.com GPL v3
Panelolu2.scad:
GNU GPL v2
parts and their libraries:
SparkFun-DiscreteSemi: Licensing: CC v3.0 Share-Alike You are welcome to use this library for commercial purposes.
